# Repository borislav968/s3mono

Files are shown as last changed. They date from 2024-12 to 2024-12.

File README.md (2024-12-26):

# Устройство согласования ЭСУД SECU-3 c моновпрысками VAG

ЭСУД SECU-3 поддерживает использование регуляторов холостого хода на основе шагового привода или электромагнита (ШИМ). Моновпрыск Bosch, применявшийся на автомобилях VAG, использует регулятор на основе коллекторного электродвигателя с обратной связью по датчику положения дроссельной заслонки, и не имеет отдельного канала холостого хода.
Для управления этим регулятором, а также согласования сигнала положения дросселя, и предназначено это устройство. Также здесь есть драйвер низкоомной форсунки.

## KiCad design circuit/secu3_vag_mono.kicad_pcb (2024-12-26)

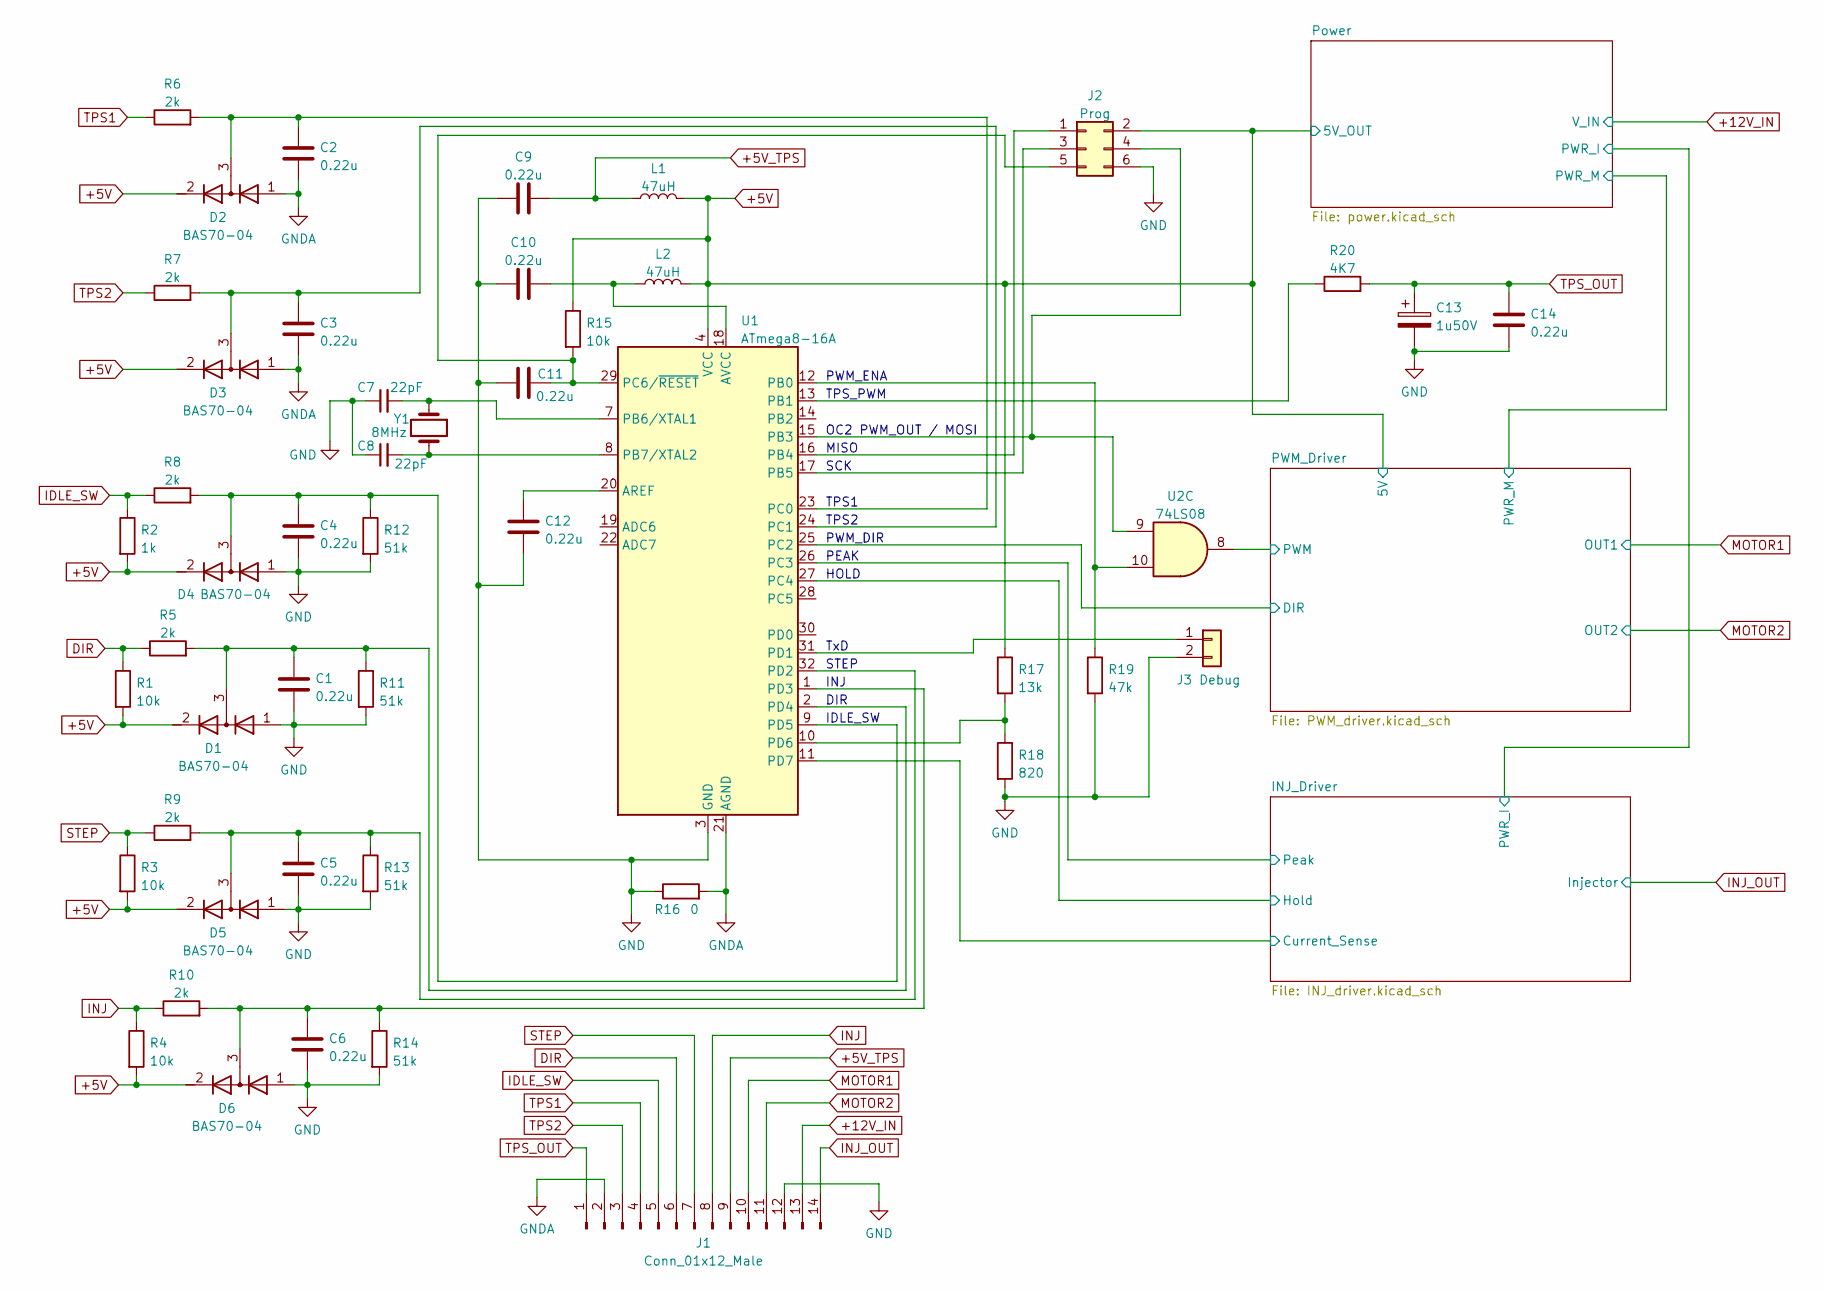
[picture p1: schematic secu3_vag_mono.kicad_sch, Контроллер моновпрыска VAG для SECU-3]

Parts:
C1, C2, C3, C4, C5, C6, C9, C10, C11, C12, C14: 0.22u; C_1206_3216Metric
C7, C8: 22pF; C_1206_3216Metric
C13: 1u50V; CP_Elec_4x5.4
D1, D2, D3, D4, D5, D6: BAS70-04; SOT-23
J1: Conn_01x12_Male; Molex_SPOX_5268-14A_1x14_P2.50mm_Horizontal
J2: Prog; PinHeader_2x03_P2.54mm_Vertical
J3: Debug; PinHeader_1x02_P2.54mm_Vertical
L1, L2: 47uH; L_1812_4532Metric
R1, R3, R4, R15: 10k; R_1206_3216Metric
R2: 1k; R_1206_3216Metric
R5, R6, R7, R8, R9, R10: 2k; R_1206_3216Metric
R11, R12, R13, R14: 51k; R_1206_3216Metric
R16: 0; R_1206_3216Metric
R17: 13k; R_1206_3216Metric
R18: 820; R_1206_3216Metric
R19: 47k; R_1206_3216Metric
R20: 4K7; R_1206_3216Metric
U1: ATmega8-16A; TQFP-32_7x7mm_P0.8mm
U2: 74LS08; SOIC-14_3.9x8.7mm_P1.27mm
Y1: 8MHz; Crystal_SMD_HC49-SD

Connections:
+5V: D1.2 (K), D2.2 (K), D3.2 (K), D4.2 (K), D5.2 (K), D6.2 (K), J2.2, L1.2, L2.2, R1.2, R2.2, R3.2, R4.2, R15.1, R17.1, U1.4 (VCC), U1.6 (VCC); also elsewhere on the board
+5V_TPS: C9.2, J1.9, L1.1
+12V_IN: J1.13; also elsewhere on the board
/INJ_Driver/Current_Sense: U1.11 (PD7); also elsewhere on the board
/INJ_Driver/Hold: U1.27 (PC4); also elsewhere on the board
/INJ_Driver/Peak: U1.26 (PC3); also elsewhere on the board
/PWM_Driver/DIR: U1.25 (PC2); also elsewhere on the board
/PWM_Driver/PWM: U2.8; also elsewhere on the board
DIR: J1.6, R1.1, R5.1
GND: C1.2, C4.2, C5.2, C6.2, C7.1, C8.1, C9.1, C10.1, C11.1, C12.1, C13.2, C14.2, D1.1 (A), D4.1 (A), D5.1 (A), D6.1 (A), J1.12, J2.6, J3.2, R11.2, R12.2, R13.2, R14.2, R16.1, R18.2, R19.2, U1.3 (GND), U1.5 (GND); also elsewhere on the board
GNDA: C2.2, C3.2, D2.1 (A), D3.1 (A), J1.2, R16.2, U1.21 (AGND)
IDLE_SW: J1.5, R2.1, R8.1
INJ: J1.8, R4.1, R10.1
INJ_OUT: J1.14; also elsewhere on the board
MOTOR1: J1.10; also elsewhere on the board
MOTOR2: J1.11; also elsewhere on the board
unnamed: C1.1, D1.3 (common), R5.2, R11.1, U1.2 (PD4)
unnamed: C2.1, D2.3 (common), R6.2, U1.23 (PC0)
unnamed: C3.1, D3.3 (common), R7.2, U1.24 (PC1)
unnamed: C4.1, D4.3 (common), R8.2, R12.1, U1.9 (PD5)
unnamed: C5.1, D5.3 (common), R9.2, R13.1, U1.32 (PD2)
unnamed: C6.1, D6.3 (common), R10.2, R14.1, U1.1 (PD3)
unnamed: C7.2, U1.7 (PB6/XTAL1), Y1.1
unnamed: C8.2, U1.8 (PB7/XTAL2), Y1.2
unnamed: C10.2, L2.1, U1.18 (AVCC)
unnamed: C11.2, J2.5, R15.2, U1.29 (PC6/~RESET)
unnamed: C12.2, U1.20 (AREF)
unnamed: J2.1, U1.16 (PB4)
unnamed: J2.3, U1.17 (PB5)
unnamed: J2.4, U1.15 (PB3), U2.9
unnamed: J3.1, U1.31 (PD1)
unnamed: R17.2, R18.1, U1.10 (PD6)
unnamed: R19.1, U1.12 (PB0), U2.10
unnamed: R20.1, U1.13 (PB1)
STEP: J1.7, R3.1, R9.1
TPS1: J1.4, R6.1
TPS2: J1.3, R7.1
TPS_OUT: C13.1, C14.1, J1.1, R20.2

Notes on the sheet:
MISO
SCK
STEP
TxD
TPS2
TPS_PWM
PWM_DIR
PEAK
IDLE_SW
HOLD
DIR
INJ
PWM_ENA
OC2 PWM_OUT / MOSI
TPS1

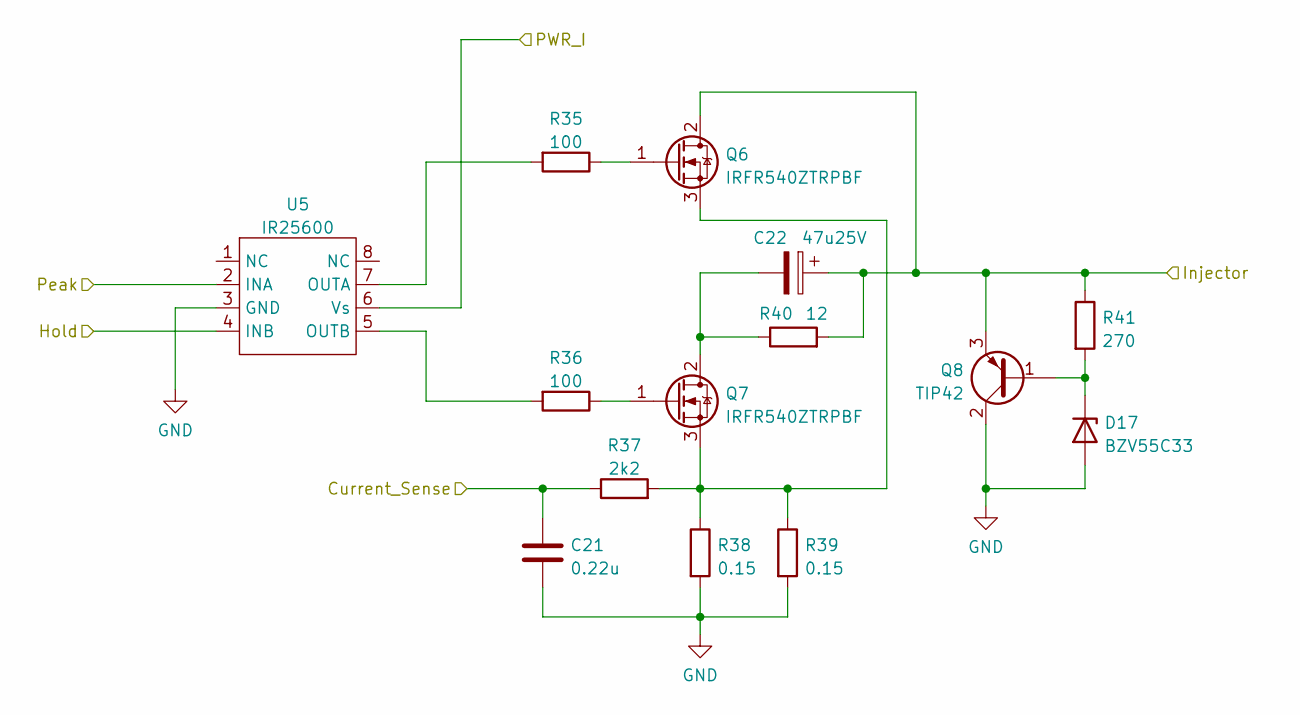
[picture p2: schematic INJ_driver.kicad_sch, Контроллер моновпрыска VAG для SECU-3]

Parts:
C21: 0.22u; C_1206_3216Metric
C22: 47u25V; CP_Elec_6.3x5.4
D17: BZV55C33; D_MiniMELF
Q6, Q7: IRFR540ZTRPBF; TO-252-3_TabPin2
Q8: TIP42; TO-220-3_Vertical
R35, R36: 100; R_1206_3216Metric
R37: 2k2; R_1206_3216Metric
R38, R39: 0.15; R_1206_3216Metric
R40: 12; R_Axial_Power_L25.0mm_W9.0mm_P30.48mm
R41: 270; R_1206_3216Metric
U5: IR25600; SOIC-8_3.9x4.9mm_P1.27mm

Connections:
/INJ_Driver/Current_Sense: C21.1, R37.1; also elsewhere on the board
/INJ_Driver/Hold: U5.4 (INB); also elsewhere on the board
/INJ_Driver/PWR_I: U5.6 (Vs); also elsewhere on the board
/INJ_Driver/Peak: U5.2 (INA); also elsewhere on the board
GND: C21.2, D17.2 (A), Q8.2 (C), R38.2, R39.2, U5.3 (GND); also elsewhere on the board
INJ_OUT: C22.1, Q6.2 (D), Q8.3 (E), R40.2, R41.1; also elsewhere on the board
unnamed: C22.2, Q7.2 (D), R40.1
unnamed: D17.1 (K), Q8.1 (B), R41.2
unnamed: Q6.1 (G), R35.1
unnamed: Q6.3 (S), Q7.3 (S), R37.2, R38.1, R39.1
unnamed: Q7.1 (G), R36.1
unnamed: R35.2, U5.7 (OUTA)
unnamed: R36.2, U5.5 (OUTB)

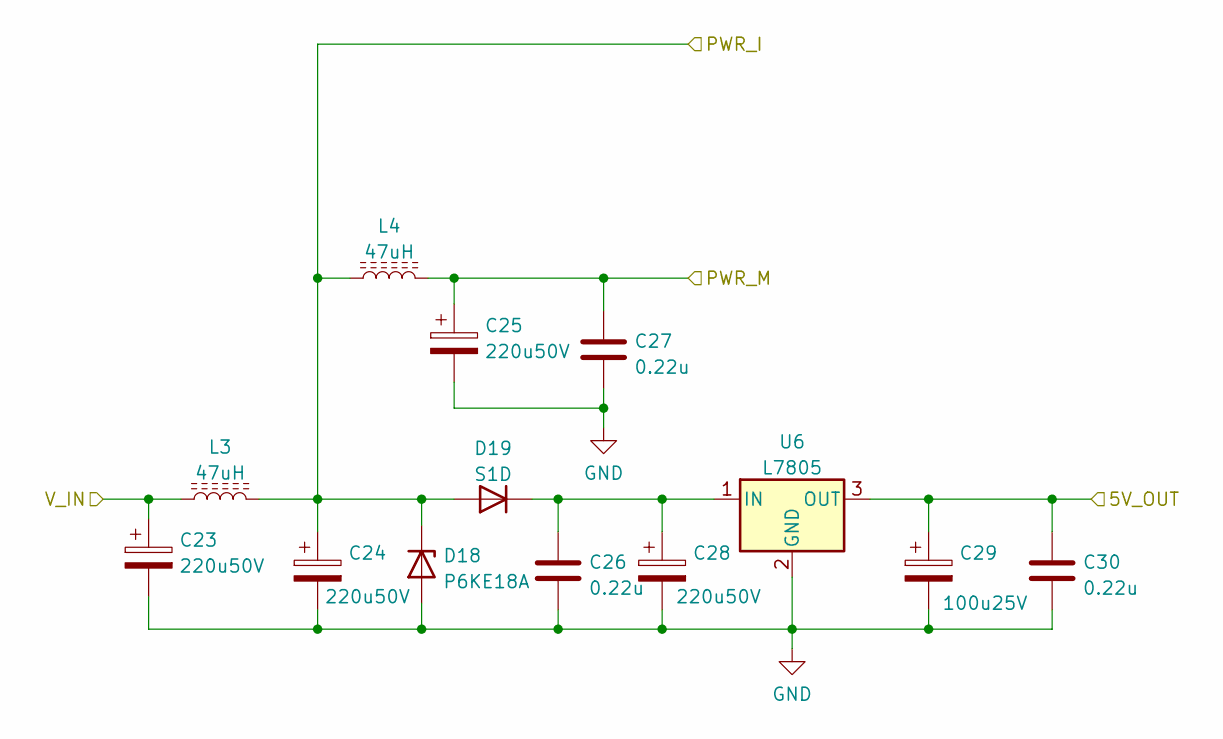
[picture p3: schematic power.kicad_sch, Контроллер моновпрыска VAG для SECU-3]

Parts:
C23, C24, C25, C28: 220u50V; CP_Elec_10x10.5
C26, C27, C30: 0.22u; C_1206_3216Metric
C29: 100u25V; CP_Elec_6.3x7.7
D18: P6KE18A; D_DO-15_P3.81mm_Vertical_AnodeUp
D19: S1D; D_SMA
L3, L4: 47uH; L_Bourns_SRR1260
U6: L7805; TO-252-2

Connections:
+5V: C29.1, C30.1, U6.3 (OUT); also elsewhere on the board
+12V_IN: C23.1, L3.1; also elsewhere on the board
/INJ_Driver/PWR_I: C24.1, D18.1 (K), D19.2 (A), L3.2, L4.1; also elsewhere on the board
/PWM_Driver/PWR_M: C25.1, C27.1, L4.2; also elsewhere on the board
GND: C23.2, C24.2, C25.2, C26.2, C27.2, C28.2, C29.2, C30.2, D18.2 (A), U6.2 (GND); also elsewhere on the board
unnamed: C26.1, C28.1, D19.1 (K), U6.1 (IN)

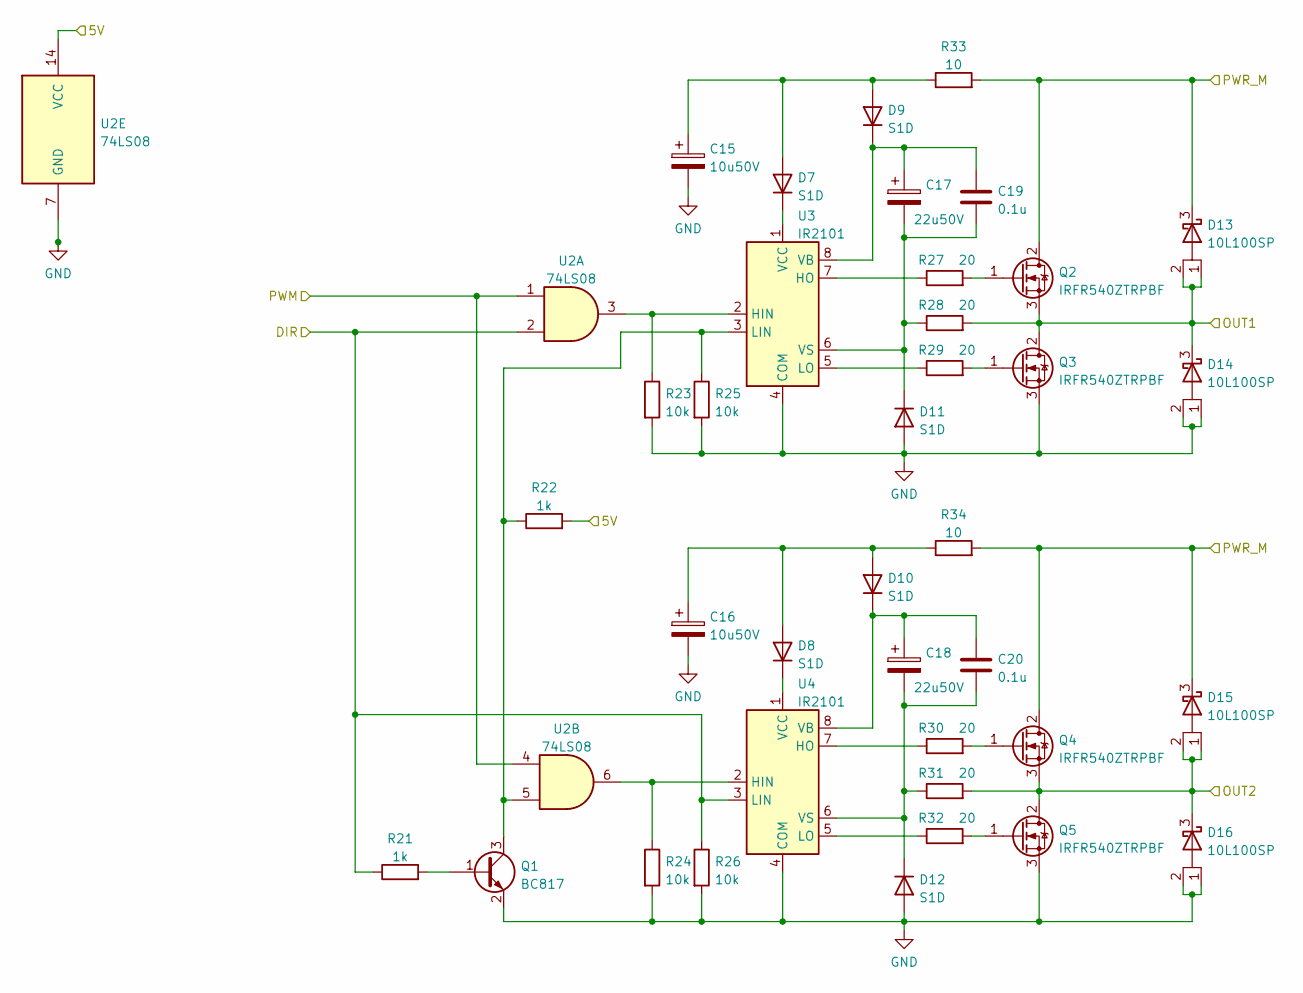
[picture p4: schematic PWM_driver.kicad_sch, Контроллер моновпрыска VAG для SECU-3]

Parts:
C15, C16: 10u50V; CP_Elec_6.3x5.4
C17, C18: 22u50V; CP_Elec_6.3x5.4
C19, C20: 0.1u; C_1206_3216Metric
D7, D8, D9, D10, D11, D12: S1D; D_SMA
D13, D14, D15, D16: 10L100SP; TO-277B
Q1: BC817; SOT-23
Q2, Q3, Q4, Q5: IRFR540ZTRPBF; TO-252-3_TabPin2
R21, R22: 1k; R_1206_3216Metric
R23, R24, R25, R26: 10k; R_1206_3216Metric
R27, R28, R29, R30, R31, R32: 20; R_1206_3216Metric
R33, R34: 10; R_1206_3216Metric
U2: 74LS08; SOIC-14_3.9x8.7mm_P1.27mm
U3, U4: IR2101; SOIC-8_3.9x4.9mm_P1.27mm

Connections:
+5V: R22.2, U2.14 (VCC); also elsewhere on the board
/PWM_Driver/DIR: R21.1, R26.1, U2.2, U4.3 (LIN); also elsewhere on the board
/PWM_Driver/PWM: U2.1, U2.4; also elsewhere on the board
/PWM_Driver/PWR_M: D13.3, D15.3, Q2.2 (D), Q4.2 (D), R33.2, R34.2; also elsewhere on the board
GND: C15.2, C16.2, D11.2 (A), D12.2 (A), D14.1, D14.2, D16.1, D16.2, Q1.2 (E), Q3.3 (S), Q5.3 (S), R23.2, R24.2, R25.2, R26.2, U2.7 (GND), U3.4 (COM), U4.4 (COM); also elsewhere on the board
MOTOR1: D13.1, D13.2, D14.3, Q2.3 (S), Q3.2 (D), R28.2; also elsewhere on the board
MOTOR2: D15.1, D15.2, D16.3, Q4.3 (S), Q5.2 (D), R31.2; also elsewhere on the board
unnamed: C15.1, D7.2 (A), D9.2 (A), R33.1
unnamed: C16.1, D8.2 (A), D10.2 (A), R34.1
unnamed: C17.1, C19.1, D9.1 (K), U3.8 (VB)
unnamed: C17.2, C19.2, D11.1 (K), R28.1, U3.6 (VS)
unnamed: C18.1, C20.1, D10.1 (K), U4.8 (VB)
unnamed: C18.2, C20.2, D12.1 (K), R31.1, U4.6 (VS)
unnamed: D7.1 (K), U3.1 (VCC)
unnamed: D8.1 (K), U4.1 (VCC)
unnamed: Q1.1 (B), R21.2
unnamed: Q1.3 (C), R22.1, R25.1, U2.5, U3.3 (LIN)
unnamed: Q2.1 (G), R27.2
unnamed: Q3.1 (G), R29.2
unnamed: Q4.1 (G), R30.2
unnamed: Q5.1 (G), R32.2
unnamed: R23.1, U2.3, U3.2 (HIN)
unnamed: R24.1, U2.6, U4.2 (HIN)
unnamed: R27.1, U3.7 (HO)
unnamed: R29.1, U3.5 (LO)
unnamed: R30.1, U4.7 (HO)
unnamed: R32.1, U4.5 (LO)

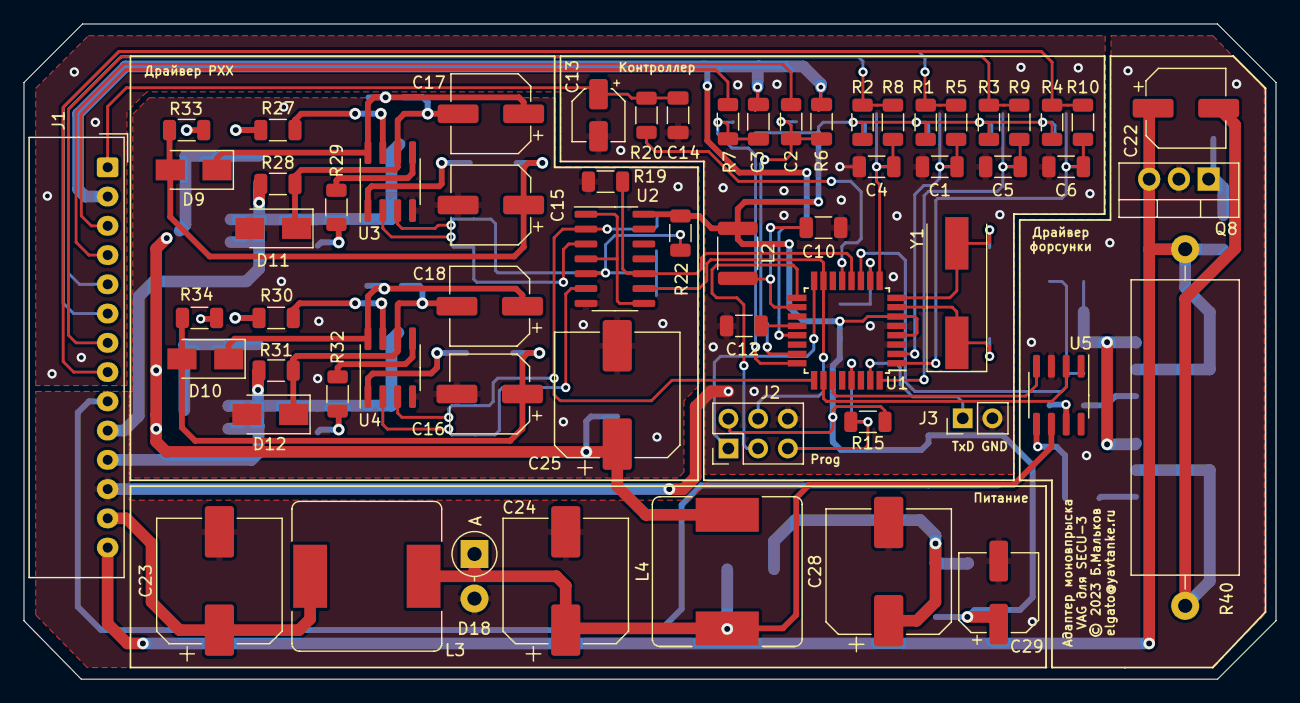
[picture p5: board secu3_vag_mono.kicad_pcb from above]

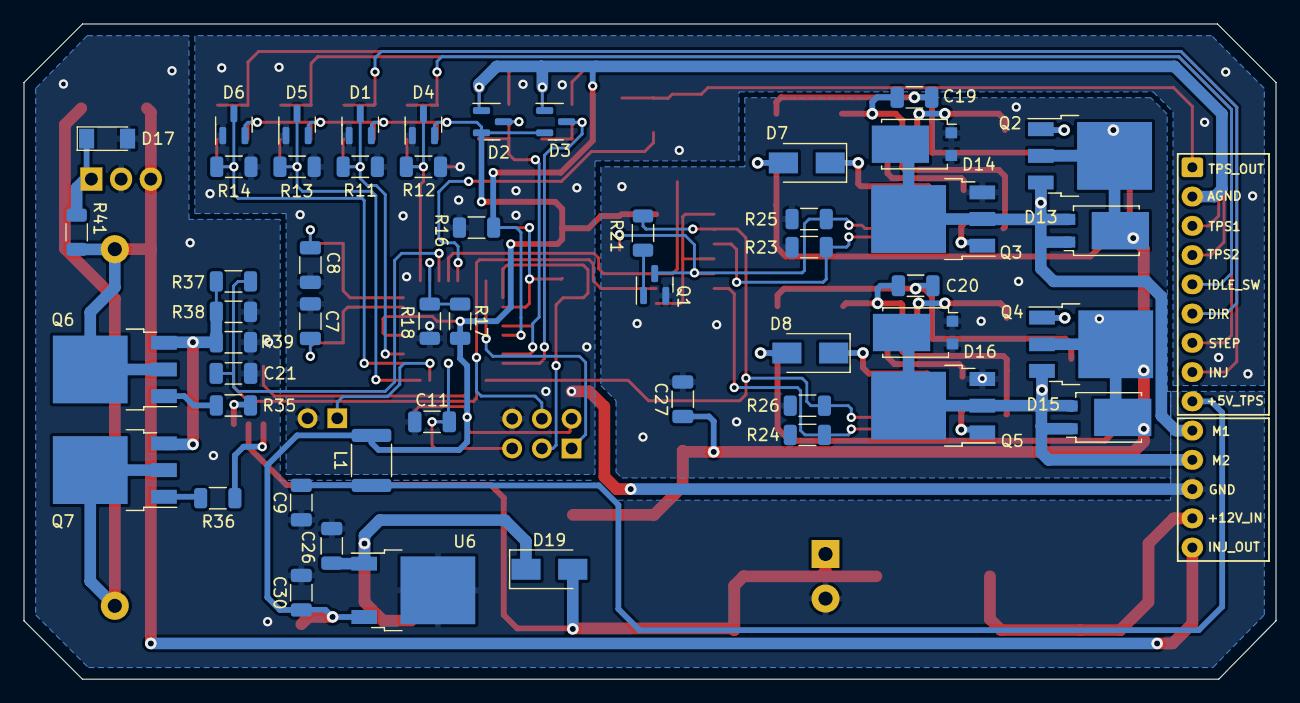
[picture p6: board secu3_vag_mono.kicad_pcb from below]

Board: 2 copper layers, 107.0 x 56.0 mm, 112 parts (51 on the bottom side), 68 nets.

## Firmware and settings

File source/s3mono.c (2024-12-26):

#include <avr/io.h>
#include <avr/interrupt.h>
#include <avr/pgmspace.h>
#include <stdio.h>
#include "config.h"
#include "uart.h"
#include "sensors.h"
#include "secu.h"
#include "motor.h"

volatile uint8_t t0_counter = 0;    // Счётчик переполнениий таймера 0
volatile uint8_t timer_main = 0;    // Счётчик главного цикла
volatile uint8_t timer_debug = 0;   // Счётчик цикла отладки (UART)

volatile uint16_t * idle_set;       // Положение РХХ


// Настройка таймера 0 (главный цикл)
void init_timer_main () {
    TIMSK |= (1<<TOIE0);            // Разрешение прерывания по переполнению
    TCCR0 |= (1<<CS01) | (1<<CS00); // Делитель частоты 64 (125кГц), переполнение ~2мс
}


// Прерывание от таймера 0 по переполнению
ISR (TIMER0_OVF_vect) {
    t0_counter++;
    if (!(t0_counter % 2)) timer_main++;        // ~4мс
    if (!(t0_counter % 128)) timer_debug++;     // ~260мс
}


int main (void) {

    // Настройка обмена с SECU-3
    init_secu_connection(&idle_set, SECU_STEPS);

    // Глобальное разрешение прерываний
    sei(); 

    // Настройка UART
    uart_init(UART_BAUD_SELECT(UART_BAUD_RATE, F_CPU));

    // Настройка таймера 0 (главный цикл)
    init_timer_main();

    // Настройка работы с датчиками
    init_sensors();

    // Настройка привода РХХ
    init_motor(K_P, K_I, MAX_SUM_ERROR, MIN_ERROR, BUMP_DETECT);
    
    
    // Подготовка терминала
    uart_puts_P("\x1b[2J");               // Очистить экран терминала
    uart_puts_P("\x9b?25l");              // Спрятать курсор
    uart_puts_P("\n\n\rAIN1\tTarget\n\r");  // "Шапка" таблицы
    
    char term_buffer[30];   // Буфер для вывода в терминал
    int16_t reg = 0;            // Воздействие регулятора
    uint16_t target_reg = 0;    // Целевое положение по 1-му датчику
    
    while (1) {
        if (timer_main) {
            target_reg = target_adc(*idle_set, SECU_STEPS);
            secu_set_tps(tps(target_reg));    // Положение ДЗ для SECU-3
            if (pedal_switch())     // Если педаль газа нажата...
                reg = 0;            // регулятор не работает
            else                    // Если педаль не нажата - это режим ХХ,
                reg = regulator(sensor0(), target_reg);  // рассчитывается воздействие регулятора
            motor(reg);             // Управление приводом
            timer_main = 0;
        }
        if (timer_debug) {
            sprintf(term_buffer, "%u   \t%u   \r", sensor0(), target_reg);
            uart_puts(term_buffer);
            timer_debug = 0;
        }
    }
    
}

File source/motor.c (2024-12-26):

#include <avr/io.h>
#include <stdlib.h>

uint16_t _k_p;
uint16_t _k_i;
uint16_t _max_sum_error;
uint16_t _min_error;
uint16_t _bump_detect;

// Настройка привода РХХ
void init_motor (uint16_t k_p, uint16_t k_i, uint16_t max_sum_error, uint16_t min_error, uint16_t bump_detect) {

    DDRB |= (1<<PB0);       // PB0 включает управление мостом
    DDRB |= (1<<PB3);       // PB3 - выход ШИМ
    DDRC |= (1<<PC2);       // PC2 - управление полярностью (направлением)
    
    PORTB |= (1<<PB0);      // включение управления
    
    // Настройка таймера 2
    TCCR2 |= (1<<WGM20);    // ШИМ с правильной фазой
    TCCR2 |= (1<<COM21);    // выход OC2 на PB3
    OCR2 = 0;               // скважность 0
    TCCR2 |= (1<<CS21);     // запуск, частота 8МГц / 8 / 256*2 = ~1.95кГц
    
    _k_p = k_p;
    _k_i = k_i;
    _max_sum_error = max_sum_error;
    _min_error = min_error;
    _bump_detect = bump_detect;
    
}


// Управление электродивгателем
// power: -255..255, знак определяет направление вращения
void motor (int16_t power) {
    // направление: состояние PC2 из знака power
    if (power < 0) PORTC |= (1<<PC2); else PORTC &= ~(1<<PC2);
    // скважность ШИМ
    OCR2 = abs(power) > UINT8_MAX ? UINT8_MAX : abs(power);
}


// Расчёт воздействия регулятора
// Возвращает значения -255..255    
int16_t regulator(uint16_t value, uint16_t control) {

    int16_t error;                  // величина ошибки
    static int16_t sum_error = 0;   // накопленная ошибка
    int16_t p_reg;                  // пропорциональный регулятор
    int16_t i_reg;                  // интегральный регулятор
    int16_t result;                 // временное размещение результатов
    // накопление ненулевого воздествия регулятора (для определения нахождения привода на упоре или заклинивания)
    static int16_t bump_counter = 0;

    // Приведение входных значений к рабочему диапазону
    if (value > 1024) value = 1024;
    if (control > 1024) control = 1024;

    error = control - value;        // вычисление ошибки
    
    if (abs(error) < _min_error) error = 0; // минимальный порог ошибки (если меньше - ошибка игнорируется)
    if (error == 0) {                   // При отсутствии ошибки...
        sum_error = 0;              // накопленная ошибка обнуляется во избеание раскачки.
        bump_counter = 0;           // ...как и счётчик нахождения на упоре
    } else
        sum_error += error;         // Накопление ошибки, когда она ненулевая.

    // Накопленная ошибка ограничивается
    if (sum_error > _max_sum_error) sum_error = _max_sum_error;
    if (sum_error < -(int32_t)_max_sum_error) sum_error = -(int32_t)_max_sum_error;
       
    p_reg = error * _k_p;               // Пропорциональный регулятор
    i_reg = (sum_error * _k_i) / 10;    // Интегральный регулятор

    result = p_reg + i_reg;             // Сумма составляющих

    bump_counter += result / 16;         // Накопление воздействия
    if (abs(bump_counter) >= _bump_detect) result = 0;   // При превышении порога регулятор отключается (перегрузка)

    // Ограничение минимального и максимального значений до -255..255
    return (result > UINT8_MAX) ? UINT8_MAX : (result < -UINT8_MAX) ? -UINT8_MAX : result;

}

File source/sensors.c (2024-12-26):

#include <avr/io.h>
#include <avr/interrupt.h>


// Входы АЦП
volatile uint16_t ain0 = 0;
volatile uint16_t ain1 = 0;

// Настройка работы с датчиками
void init_sensors () {
    // АЦП
    ADMUX = (1<<REFS0);     // опорное напряжение от вывода AVCC (5В)
    ADCSRA |= (1<<ADPS2) | (1<<ADPS1);  // делитель 64 (125кГц)
    ADCSRA |= (1<<ADIE);    // разрешение прерывания от АЦП
    ADCSRA |= (1<<ADFR);    // режим постоянной работы
    ADCSRA |= (1<<ADEN);    // включение АЦП
    ADCSRA |= (1<<ADSC);    // запуск первого преобразования
}


#define min0 0
#define max0 1013
#define max_reg 840
#define max_tps0 127

#define min1 148
#define max1 864
#define max_tps1 128


// Прерывание от АЦП
ISR (ADC_vect) {
    static uint8_t counter = 0;     // счётчик измерений
    // Результат первого измерения после переключения каналов недостоверен
    if (counter++ & 1) return;  // ...поэтому игнорируется
    // Результат каждого второго измерения можно использовать
    if (counter & 2) {          // бит 1 определяет, на каком из каналов АЦП измеряем
        ain0 = ADC;             // получение результата в ain0
        if (ain0 < min0) ain0 = min0;
        if (ain0 > max0) ain0 = max0;
        ADMUX |= (1<<MUX0);     // переключение на 1-й канал
    } else {
        ain1 = ADC;             // получение результата в ain1
        if (ain1 < min1) ain1 = min1;
        if (ain1 > max1) ain1 = max1;
        ADMUX &= ~(1<<MUX0);    // переключение на 0-й канал
    }    
}

// Вычисление положения заслонки
uint8_t tps (uint16_t reg_tps) {
    uint8_t tps0, tps1;
    uint8_t position;
    uint8_t reg_part;
    // интерполяция первого датчика
    tps0 = ((uint32_t)max_tps0 * (ain0 - min0)) / (max0 - min0);
    // интерполяция второго датчика
    tps1 = ((uint32_t)max_tps1 * (ain1 - min1)) / (max1 - min1);
    // проверка допустимости значения reg_tps
    if (reg_tps > ain0) reg_tps = ain0;
    // положение регулятора в 1/255
    reg_part = ((uint32_t)max_tps0 * (reg_tps - min0)) / (max0 - min0);
    // положение заслонки с учётом регулятора в 1/255
    position = tps0 + tps1 - reg_part;
    // приведение к диапазону 1..255
    position = ((uint32_t)position * 255) / (255 - reg_part);

    return position;
}

// Вычисление целевого положения по 1-му ДПДЗ
// value: текущее число шагов, range - полное число шагов
uint16_t target_adc(uint16_t value, uint16_t range) {
    if (value > range) return range;
    return ((uint32_t)value * (max_reg - min0)) / range;
}

uint16_t sensor0 () {
    return ain0;
}

uint16_t sensor1 () {
    return ain1;
}

// Состояние концевика заслонки
uint8_t pedal_switch () {
    return (PIND & (1<<PD5)) ? 1 : 0;
}

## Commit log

2024-12-26 Исходные тексты
2024-12-26 Схема платы
    [INJ_driver.kicad_sch, PWM_driver.kicad_sch, power.kicad_sch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]
2024-12-26 Определение имени проекта

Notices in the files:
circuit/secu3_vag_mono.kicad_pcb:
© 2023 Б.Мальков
